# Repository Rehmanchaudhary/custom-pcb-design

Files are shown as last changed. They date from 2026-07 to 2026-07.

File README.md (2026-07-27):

# Custom PCB Design — Arduino Nano Clone

Full schematic and PCB layout design of an Arduino Nano–compatible board, designed
from scratch in KiCad, physically etched, soldered, and tested.

## What's Included
- `Arduino_Nano.kicad_sch` — full schematic
- `Arduino_Nano.kicad_pcb` — routed PCB layout (39 components placed)

## Key Components
- **ATmega328P** — main microcontroller
- **FT232RL** — USB-to-serial converter for programming/communication
- **LM1117MP-5.0** — 5V linear voltage regulator
- **USB Mini-B connector** — power and data
- **16MHz crystal resonator** — clock source
- Supporting passives: resistors, capacitors, status LEDs, polyfuse, reset switch

## How It Works
The design replicates the core architecture of an Arduino Nano: USB power and
serial communication are handled by the FT232RL, which bridges to the ATmega328P
over its UART pins for programming. The LM1117 regulates incoming USB 5V down to
a clean supply rail for the logic, with decoupling capacitors placed close to
each IC to maintain signal integrity. The resonator provides the microcontroller's
clock signal.

## Process
1. Schematic capture in KiCad — placing and wiring all components with correct
   pin assignments and power nets
2. PCB layout — routing traces, placing components, checking for clearance/DRC
   errors
3. Physical fabrication — etching the board
4. Assembly — soldering all components onto the etched board
5. Testing — verifying continuity and functionality of the assembled board

## Tech Stack
`KiCad` `PCB Design` `Schematic Capture` `Circuit Etching` `Soldering`

## What I Learned
Routing traces without accidental shorts was the hardest part of the layout stage —
with a board this dense (39 components including a microcontroller, USB-to-serial
chip, and voltage regulator), keeping enough clearance between traces while still
routing everything cleanly took several passes through KiCad's design rule checker.
Etching and soldering the physical board afterward made clear how much a clean
schematic and layout actually matters — any mistake at the design stage becomes a
much harder problem to fix once it's etched into copper.

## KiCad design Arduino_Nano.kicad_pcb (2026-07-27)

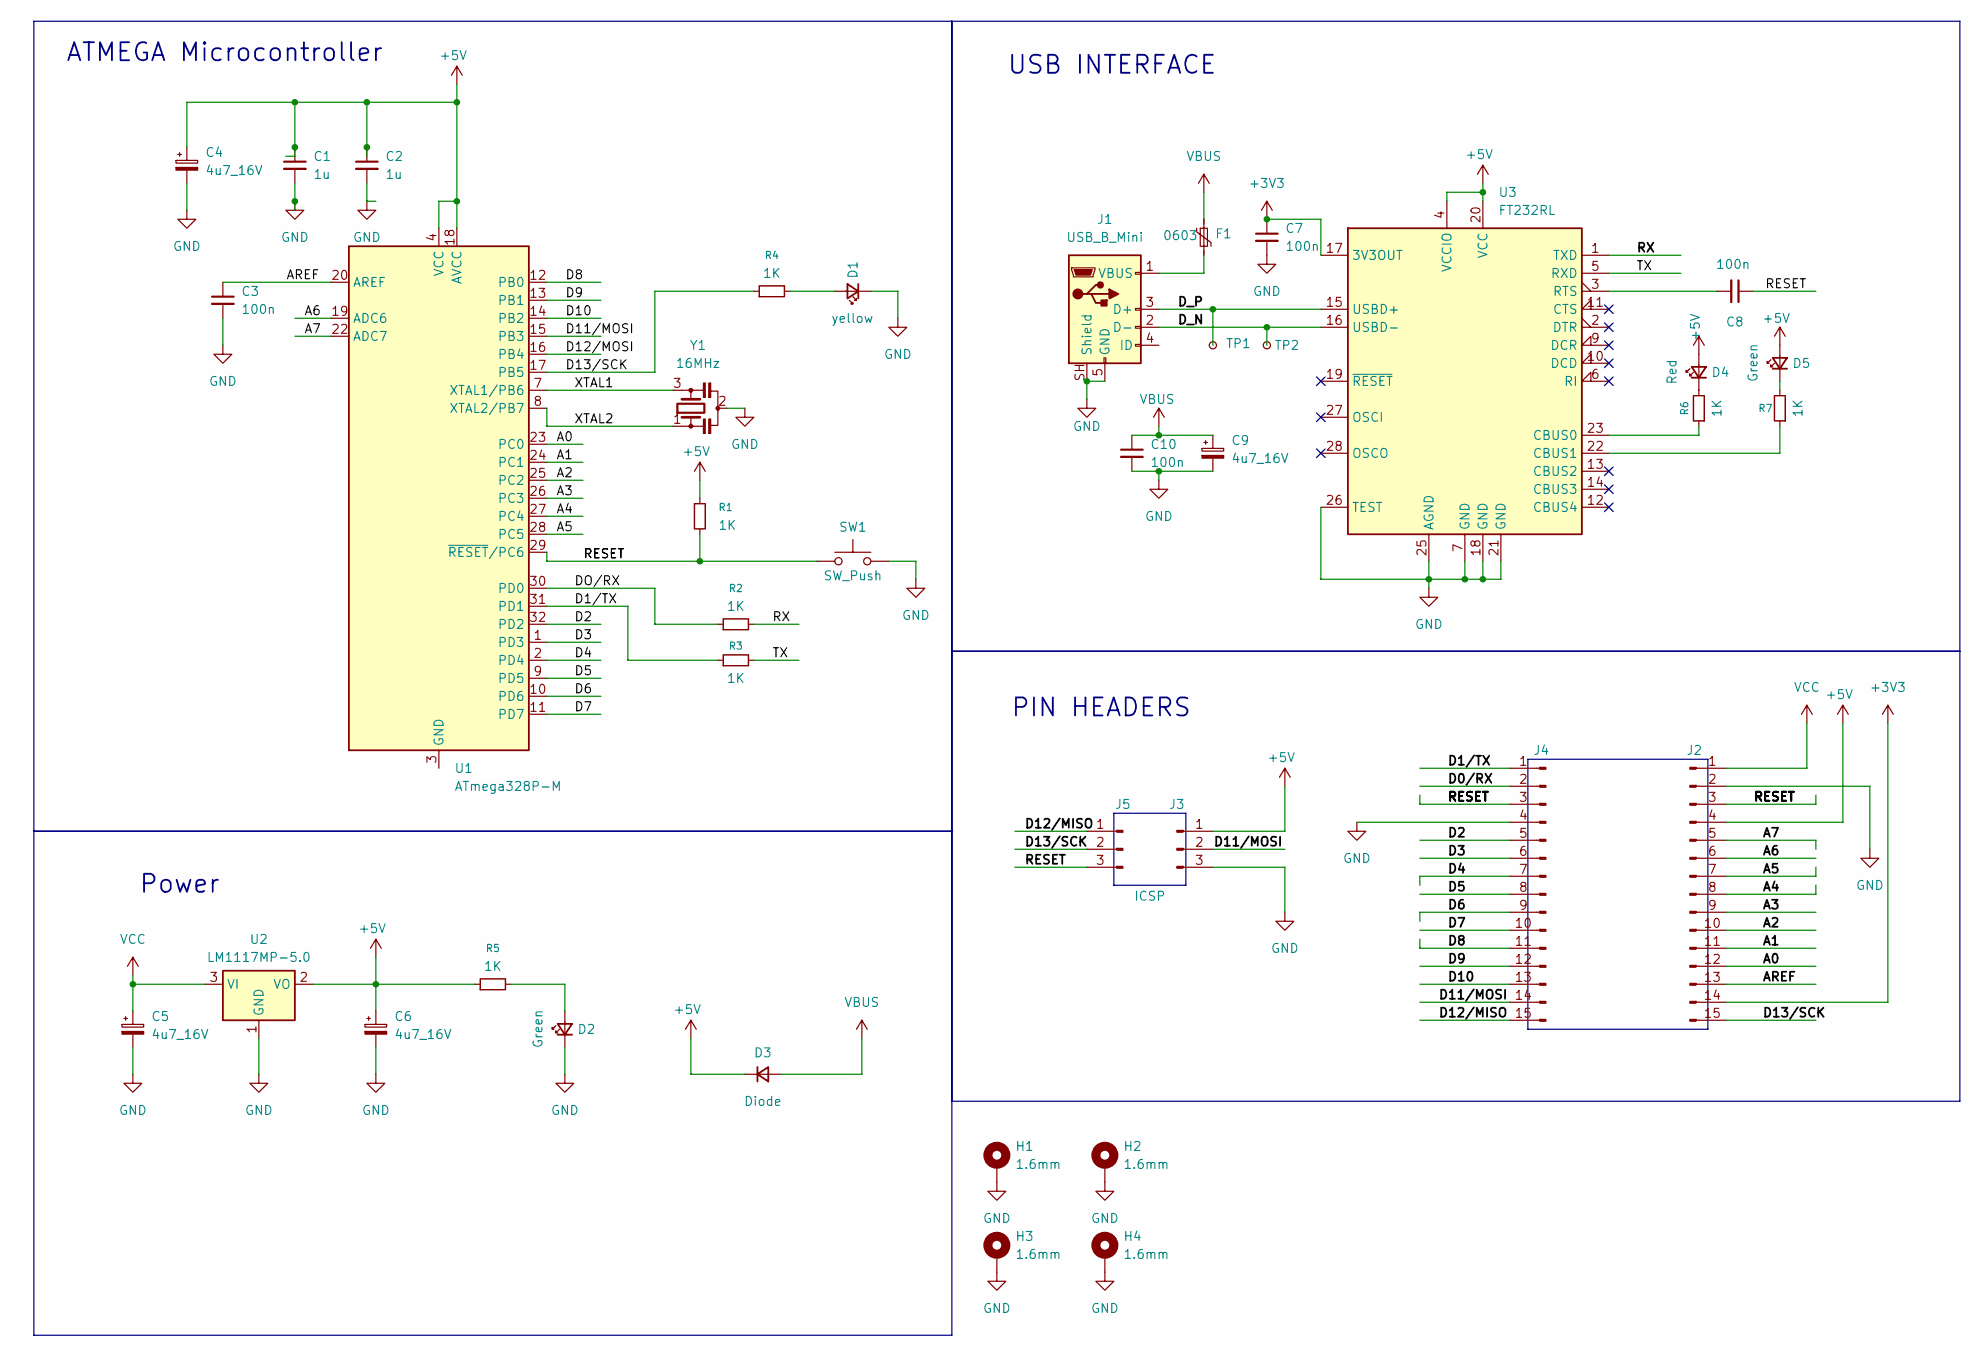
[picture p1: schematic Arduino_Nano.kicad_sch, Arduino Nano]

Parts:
C1, C2: 1u; C_0805_2012Metric
C3, C7, C10: 100n; C_0805_2012Metric
C4, C5, C6, C9: 4u7_16V; C_0805_2012Metric
C8: 100n; CP_EIA-3216-18_Kemet-A
D1: yellow; LED_0805_2012Metric
D2, D5: Green; LED_0805_2012Metric
D3: Diode; D_SOD-123
D4: Red; LED_0805_2012Metric
F1: 0603; Fuse_0603_1608Metric
H1, H2, H3, H4: 1.6mm; MountingHole_3.2mm_M3_DIN965_Pad
J1: USB_B_Mini; USB_Mini-B_Lumberg_2486_01_Horizontal
J2, J4: PinHeader_1x15_P2.54mm_Vertical
J3: ICSP; PinHeader_2x03_P2.54mm_Vertical
J5: PinHeader_1x03_P2.54mm_Vertical
R1, R2, R3, R4, R5, R6, R7: 1K; R_0805_2012Metric
SW1: SW_Push; SW_SPST_TL3342
TP1, TP2: TestPoint_Pad_D1.5mm
U1: ATmega328P-M; TQFP-48-1EP_7x7mm_P0.5mm_EP5x5mm
U2: LM1117MP-5.0; SOT-223-3_TabPin2
U3: FT232RL; SSOP-28_5.3x10.2mm_P0.65mm
Y1: 16MHz; Crystal_SMD_SeikoEpson_FA128-4Pin_2.0x1.6mm

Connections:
+3V3: C7.1, J2.14, U3.17 (3V3OUT)
+5V: C1.1, C2.1, C4.1, C6.1, D3.1 (K), D4.2 (A), D5.2 (A), J2.4, J3.1, R1.1, R5.1, U1.4 (VCC), U1.6 (VCC), U1.18 (AVCC), U2.2 (VO), U3.4 (VCCIO), U3.20 (VCC)
/A0: J2.12, U1.23 (PC0)
/A1: J2.11, U1.24 (PC1)
/A2: J2.10, U1.25 (PC2)
/A3: J2.9, U1.26 (PC3)
/A4: J2.8, U1.27 (PC4)
/A5: J2.7, U1.28 (PC5)
/A6: J2.6, U1.19 (ADC6)
/A7: J2.5, U1.22 (ADC7)
/AREF: C3.1, J2.13, U1.20 (AREF)
/D0/RX: J4.2
/D1/TX: J4.1, R3.1, U1.31 (PD1)
/D2: J4.5, U1.32 (PD2)
/D3: J4.6, U1.1 (PD3)
/D4: J4.7, U1.2 (PD4)
/D5: J4.8, U1.9 (PD5)
/D6: J4.9, U1.10 (PD6)
/D7: J4.10, U1.11 (PD7)
/D8: J4.11, U1.12 (PB0)
/D9: J4.12, U1.13 (PB1)
/D10: J4.13, U1.14 (PB2)
/D11/MOSI: J3.2, J4.14, U1.15 (PB3)
/D12/MISO: J4.15, J5.1
/D12/MOSI: U1.16 (PB4)
/D13/SCK: J2.15, J5.2, R4.1, U1.17 (PB5)
/DO/RX: R2.1, U1.30 (PD0)
/D_N: J1.2 (D-), TP2.1 (1_1), U3.16 (USBD-)
/D_P: J1.3 (D+), TP1.1 (1_1), U3.15 (USBD+)
/RX: R2.2, U3.1 (TXD)
/TX: R3.2, U3.5 (RXD)
/XTAL1: U1.7 (XTAL1/PB6), Y1.3
/XTAL2: U1.8 (XTAL2/PB7), Y1.1
GND: C1.2, C2.2, C3.2, C4.2, C5.2, C6.2, C7.2, C9.2, C10.2, D1.1 (K), D2.1 (K), H1.1 (1_1), H2.1 (1_1), H3.1 (1_1), H4.1 (1_1), J1.5 (GND), J1.SH (Shield), J2.2, J3.3, J4.4, SW1.2, U2.1 (GND), U3.7 (GND), U3.18 (GND), U3.21 (GND), U3.25 (AGND), U3.26 (TEST), Y1.2
unnamed: D1.2 (A), R4.2
unnamed: D2.2 (A), R5.2
unnamed: D4.1 (K), R6.2
unnamed: D5.1 (K), R7.2
unnamed: F1.2, J1.1 (VBUS)
unnamed: U1.3 (GND), U1.5 (GND), U1.21 (GND), U1.33 (GND)
unnamed: R6.1, U3.23 (CBUS0)
unnamed: R7.1, U3.22 (CBUS1)
unnamed: C8.2, U3.3 (RTS)
VBUS: C9.1, C10.1, D3.2 (A), F1.1
VCC: C5.1, J2.1, U2.3 (VI)

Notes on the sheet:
Power
PIN HEADERS
ATMEGA Microcontroller
USB INTERFACE

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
Board: 2 copper layers, 39 parts (0 on the bottom side), 45 nets, no tracks yet.
